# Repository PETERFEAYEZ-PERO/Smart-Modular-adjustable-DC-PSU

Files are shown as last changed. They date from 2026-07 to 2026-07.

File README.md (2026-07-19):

Here is a fully DC power supply with implemented Safety features, real-time MCU control, Voltage & Current adjustment, a cooling system, a wireless charger, and a TFT Display for output voltage.



#  Adjustable Smart Bench PSU

A modular laboratory power supply designed from scratch with
real-time monitoring, protection systems, and scalable multi-output architecture.

# Contents:

1- The main identity and features                                                                              
2- Why DIY, not buy a new, ready-made one?                                                                      
3- list of materials and cost                                                                        
4- The System Architecture flow                                                               
5- The main system Parameters                                                               
6- The automation and building process (METHODS)                                                               
7- Coding-related Part                                                               
8- Documented Failures                                                               
9- Outcome                                                               
10- Safety features and precautions                                                               
11- Upcoming Progress                                                               
12- References                                                               
13- ###<strong>Acknowledgments, refreneces, and AI usage </strong>                                                               
14- Contact                                                               
15- License                                                               

## The Main identity and features:

I had always dreamed about owning an awesome power supply for my projects, a cable to handle various projects, ideas, and testing loads.
Unfortunately, the features, design, and flexibility I need would cost me a lot of money. So I decided to make my own. Additionally, since I had no workshop, tools, devices, or anything, I found it cool to make a full series about building my lab. 

### The Features I was dreaming about:                                                               
1- Adjustable DC power supply ranging from Lim➡️ ZERO to 24V.                                                               
2- Multi-port for output like 4 or 5.                                                               
3- TFT screen of 3.4 inches, rather than 7-segment.                                                               
4- Nice Design.                                                               
5- High Safety features.                                                               
6- one or two AC Ports.                                                               
7- integrated USB HUB                                                             
7- Wireless Charger.                                                               
8- Cooling System.                                                               
9- Data Logging, Graphing, and connection to PC or Lab capability.                                                               
10- Desktop APP                                                               
11- Short Circuit prevention.
12- Battery Charging.                                                               
13- Cable for Modification.                                                                
14- OverVoltage Protection (OVP), OverCurrent protection (OCP), and OverTemperature Protection (OTP)                               
15- Reverse polarity protection
16- Port protection by relay
17- Enclosure design

To find these features in PSU today, it would cost about 10,000 to 30,000 EGP, which is quite expensive for beginners.
For that sake, I made the Making My Lab series, where I will make a full lab device open-sourced for all around the world.
Additionally, you don't have to make the full project; there are versions of this project and other combinations I will provide through the journal file, and the system architecture part in that Readme, so make whatever you need. Also, I am available all of the time to answer your questions and give you help❤️ in any kinda of project, whatever it is. Just Feel Free to go for the Contact part.

## Why DIY, not buy a new, ready one??                                                             
Some people may disagree with my point of view as a maker, and someone aspires to become a mechatronics engineer like me. However, the main purpose for any project u will ever make is to *learn new kinda of stuff!!*

Is that all?    *For sure no!*
The customization and the flexibility are also important points to take into consideration with respect to the needs and price.

## The schematics




## List of materials and cost                                                                        
### The Power section:
#### DC section:-
1) Power Adaptor AC to DC 24V and 10A
2) Power adaptor AC to DC 12V and 5A                                                              
4) XL4016 DC to DC buck converter for each adjustable port                                                                 
6) Terminal Blocks + connectors
7) Wiring
8) Ports                                              

#### AC Power Section:-
External three-AC power strip

#### Wireless Charger module:-
Wireless Charger Module

### The Controlling section:-

1)- THE Microcontroller (MCU):                                    
<ul>
<li> ESP 32 (in case of making the final version)</li>
or 
<li>just any MCU (unless it fits the main parameters of the project)</li>
</ul>

2)- Current Sensor:
<ul>
<li>ACS 712</li>
</ul>

3)- Voltage Calibration circuit (Voltage Divider):-
<incline> under research until now </incline>

4)- Liquid Crystal Display (LCD):
Simply to display the voltage and current for every port, additionally warning in case a short circuit occurs.

5)- Buzzer:
For a short-circuit warning.

6)- Relay module (Fuse integrated) for every port of DC and the wireless charger.

7)- Switch per every DC and the wireless charger.

8)- Circuit of continuous control for the fans and cooling.

### 🌡️ Cooling system & seafty control:

#### Cooling System:
<ol>
<li>SSR Heatsink</li>
<li>Two or three Fans</li>
</ol>

And right here, I made many ventilation holes for the fans, like what is there in the upper case of the USB hub and the PSU too. Additionally, two ventilation holes in the back of the PSU.

#### safety control:
<ol>
<li><strong> Main fuse after the power Adapter </strong></li>
<li>May be added a fuse to every port</li>
</ol>
</br>

# The system architecture flow:
## The power Circuit:
the power shematic drawio

I made this using Draw.io.

## The automation and building Instructions:

### The PSU main Power input and protection
Here are all the instructions u are gonna need:
First of all, for the main power source, I will be using a ready-made Power Adapter of 24 V and 10 A (u could for sure get a better one till 32V as maximum and maybe till 12 amperes. However u will need proper cooling)
Secondly, the Protection circuit, where the (by the same order):
<ol>
  <li>Main Fuse <em>-it is better to use an 11 or 12 amp slow-blow fuse if u are gonna make the system with 10 amps-</em></li>
  <li>A switch -make sure u choose a switch typically to the system power input, or simply choose this switch which cable to shut off, even 220 V and 10 amps-
    
  <li>Transient protection aligned with decoupling capacitors, and yes, I am talking about surge transient protection, not just any overvoltage so make sure u are using transient diode </li>
  <li>Then here is our main system power input of 24v and 10 amps</li>
  

  <li>Finally, i added a relay as a way to shut down the whole system, ensuring safety. In case anything happens.
  I am here controlling the relay with something like an AND gate with an independent switch, and an ESP signal too. We will use the ESP for the relay in case of reverse polarity, overcurrent, overvoltage, or any severe cases. And as far as we go and make an app, we will be able to use WIFI to control the whole system</li>
  
</ol>

### The Power distribution and Outputs:
For the adjustment outputs, I will be using XL4016 for each adjustable output, and I will make them in parallel, for sure so they will all take the same voltage, and the current will be distributed.

And as seen above in the image, I also have one extra constant output taking from the main rail. In conclusion, we have three adjustable outputs and one fixed output.

Additionally, I will be using Relay for each port to manually close and open, or using WIFI.


### The power sensing for each Output:
Think of this as a way for self-parameter monitoring, where the system flows through each port and the total voltage-current consumption.

<strong>For this project, mainly I WILL USE ADC THE MOST, SO I DECIDED TO USE READY ADS MODULE 1115. Just as an alternative to the noisy ESP ADC</strong>

#### For the Current sensing for each port for the XL4016 using ACS712:


Additionally, I will be using a capacitor for each sensor to filter the noise as much as possible. You could simply use this equation to calculate your values. Since the ACS712 also uses a 5V signal, which isn't proper for the ESP PINS, I made all of the signal outputs with 3.3v using voltage dividers.


#### However, for the voltage sensing, I will be using a normal voltage divider connected to the ADS module 1115, like that:


### Then, we finally finished our Power circuit:


## The Control circuit:
The main idea of the PSU is adjustment for the outputs, so how will this work using those XL4016 modules?


The solution is to remove the Timer potentiometer, with a varying DC source of reference 1.25v. However, for the NPN injection transistor or MOSFET, it wouldn't go well.
Thus, after a long search and verification, including the use of Claude, I found that the trimmers can be replaced with a DC source at 1.25V.
So, I used an RC decoupled filter and PWM from the ESP pin; the PWM was filtered to be pure controlled DC.

### Encoders:

And this encoder circuit is mainly for adjustment, where the up and down represent decreasing and increasing the voltage or the current at each port.
Then we need 6 encoders overall.

### Heat sensor and Cooling system:
Here it is, preferable to use an NTC thermistor near the XL4016 modules, and here is the circuit


And for the coolling i made two already open fans, and I added a switch just in case I need to shut them off.

which will be implemented in the back of the PSU.


and one other fan that is working in continuous control with real time montiroing form the ESP directly proportional to the heat in a fully optimal range.

which will be implemented in the upper enclosure of the PSU


### THE ADS module 1115:
Working via I2C


### The power source for the control circuit:
where we got 5v from a LM259 buck converter, aligned with another external power adapter of 12v and 3.3v, also using an LDO voltage regulator.


### The reverse polarity circuit and buzzers:


The full control circuit, except for the ESP:


## The enclosure and 3d printing:
The idea is overall based on modularity, so I decided to make the enclosure of separate parts just in case I need to change a specific part.

### The Upper Part:



### the Bottom part:




### The back part:



### The front part:



### The assembling way:


THEN




THEN



Then, the final assembly:




For assembling the 3D case, I am gonna use a silicone paste. Additionally, the RGB light will be rounded and immersed in the edges of the upper and bottom enclosures. 
And for the outputs of the PSU, I will be using 4 mm Safety Banana Binding Posts and GX16-2

#Acknowledgments and AI usage:
<ul>
<li>My friend SID Batra: the first one who reviewed my early schematics.</li>

<li>those incredible references:</li>
<ol>
  <li> Practical electronics for inventors</li>
  <li>fundamentals of electronic circuits, especially for the FB circuits</li>
</ol>

<li>and Claude AI for the following:
<ol>
<li>Explaining the PID with Simple coding.</li>
<li>Major help in the PID coding part</li>
<li>and most importantly, the CC and CV controlling. I spent a week entirely trying to figure out the way of controlling the XL4016, and yeah, after long frustration through OP-AMPS, FB circuits, and the TL431 architecture. I just found it is better to replace the trimmers with a varying DC voltage source at the wiper</li>
</li>
</ol>
</ul>

###FUN FACT: also, the trimer potentiometer <strong>can't</strong> be replaced by the following for controlling:
<ul>
<li>NPN injection transistor, as it is non-linear and is affected by temperature  change</li>
  <li>same as the same as MOSFET </li>
</ul>

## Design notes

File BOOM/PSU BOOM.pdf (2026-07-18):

# PSU BOOM

- Power Adapter 24V 10A | : 700 EGP y
- 2 * Fuse 10A - Slow blow | : 5EGP
- 2 * Fuse 5A - Slow blow | : 5EGP
- 5 * Fuse Pocket | : 150EGP | (RAM electronics) (https://www.ram-e-shop.com/ar/shop/fuse-pocket5-ver-fuse-pocket-holder-external-for-t5x20-size-vertical-type-5-wqf-8472)
- 2 * Switch with LED | : 20EGP | (RAM electronics) (https://www.ram-e-shop.com/ar/shop/sw1-red-sw1-on-off-switch-with-led-copper-terminals-5735?category=136)
- 3* TVS Doide SMBJ26A | : 17EGP + shipping (AEtronix) (https://eg.aetronix.com/product/taiwan-semiconductor-company/smbj28a/diode-smbj28a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)
- Capacitor kit | : 1505EGP + shipping
Electrolytic cap kit 1105egp (amazon) (https://www.amazon.eg/-/en/Electronics-Capacitor-Assortment-0-1uF-1000uF-10V-50V/dp/B0FDM2MY77) + Cermic cap kit 400egp (amazon) (https://www.amazon.eg/-/en/LIFANG-18values-Monolithic-Capacitor-20pF-1uF/dp/B08CDFZYYC)
- Resistors kit | : 250EGP (RAM) (https://www.ram-e-shop.com/ar/shop/kit-resistor-525-box-of-525-carbon-resistors-1-tolerance-1-4w-lb-mqwmt-qym-mshkl-bdq-ly-1-rb-wt-7642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)
- 6 * Rotary Encode Knob | : 5EGP (RAM) (https://www.ram-e-shop.com/ar/shop/nop-round-knob-for-rotary-potentiometers-kr-bwtynshywmtr-dwr-6639)
- Jumper wires female-female | : 35EGP (RAM) (https://www.ram-e-shop.com/ar/shop/ph62-ff-20cm-ph62-20cm-female-to-female-40-jumper-wires-set-7189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)
- Jumper wires male-male | : 35EGP (RAM) (https://www.ram-e-shop.com/ar/shop/ph61-mm-20cm-ph61-20cm-male-to-male-40-jumper-wires-set-7094?category=36)
- Jumper wires male-female | : 35EGP (RAM) (https://www.ram-e-shop.com/ar/shop/ph60-mf-20cm-ph60-20cm-male-to-female-40-jumper-wires-set-7066?category=36)
- Male Head to Crocodile Alligator Clip: 85EGP (RAM) (https://www.ram-e-shop.com/ar/shop/ph71-m-cro-30cm-ph71-10pin-male-head-to-crocodile-alligator-clip-30cm-long-9197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)
- 4 * End Alligator clip cable black : 280egp (Future electronics) (https://store.fut-electronics.com/collections/cables-connectors/products/copy-of-end-alligator-clip-cable)
- 4* XT60 male to crocodile : 480 EGP (Future electronics) (https://store.fut-electronics.com/collections/cables-connectors/products/xt60female-connector-with-wire-amass-copy-copy)
- Connectors&screw blocks : 100EGP (RAM + Flux)
- Heat shrink kit : 150EGP (RAM) (https://www.ram-e-shop.com/ar/shop/h-sh-set-530-color-box-of-heat-shrink-530pcs-set-color-lb-shrnk-mkrwn-hrry-ll-zl-mlwn-530-qt-7712)
- Wire Ferrules | : 80EGP +shipping (amazon) (https://www.amazon.eg/-/en/Terminal-Insulated-Connecting-Connectors-E1006/dp/B0DRGPMXJ8?th=1)
- Heat Transfer Paste | : 250EGP (RAM) (https://www.ram-e-shop.com/ar/shop/compound-aptl-paste-50gm-heat-transfer-paste-50gm-thermal-grease-nbwb-lsq-wm-jwn-hrry-llmbrdt-llwmnywm-8890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)
- Soldering wire : 400EGP (RAM) (https://www.ram-e-shop.com/ar/shop/solder-wire-ram-100gm-solder-wire-ram-high-quality-100gm-sn70-pb30-qsdyr-lhm-ly-ljwd-mrk-rm-bkr-100jm-nsb-lqsdyr-l-lrss-70-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)
- Solder Weck : 110 EGP (RAM) (https://www.ram-e-shop.com/ar/shop/atten-at0815-wicker-atten-r-at-0815-solder-wicker-width-0-8mm-length-1-5m-shyld-qsdyr-lfk-lhm-lmkwnt-mrk-tyn-9583)
- Flux : 185 EGP (RAM) (https://www.ram-e-shop.com/ar/shop/solder-paste-blue-50gm-xg-50-repair-soldering-solder-past-welding-35g-m-jwn-qsdyr-llslht-wllhm-wzn-35-jm-6966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)
- Rounded sponge : 15 EGP (RAM) (https://www.ram-e-shop.com/ar/shop/sponge-50mm-china-replacement-sponge-for-soldering-iron-stand-round-50mm-sfnj-hml-kwy-dyry-qtr-50mm-5740)
- ZENER DIODE ASSORTMENT PACK: 115EGP (UGE) (https://uge-one.com/product/2-4v-33v-0-5w-zener-diode-assortment-pack-25-values-pack-of-250-pcs/)
- 4 * XL4016 | : 215 (Ampere) (https://ampere-electronics.com/product/xl4016-dc-dc-step-down-converter-module-12a-300w/)
- 5 * ACS712 current sensor | : 500 (RAM) (https://www.ram-e-shop.com/ar/shop/kit-cs-dc-30a-acs712-ac-dc-30a-current-sensor-module-acs712-30a-7277)
- 6 * Switch | : 30EGP (RAM) (https://www.ram-e-shop.com/ar/shop/sw2-black-2pin-sw2-on-off-switch-2-pin-copper-terminals-5736)
- Relay 4 Channel Module : 130EGP (AMPERE) (https://ampere-electronics.com/product/relay-module-4-channel-5vdc/)
- 3 * LM2596s buck converter : 135EGP (RAM) (https://www.ram-e-shop.com/ar/shop/dc-dc-100-dc-dc-step-down-converter-adjustable-3a-lm2596s-4-38vdc-to-1-5-35vdc-sku-dc100-bwrd-dyr-khfd-jhd-fwlt-7257)
- 4 * Rotary encoder | : 100 (RAM) (https://www.ram-e-shop.com/ar/shop/pot-ec11-rotary-5pin-20mm-ec11-rotary-encoder-with-push-button-switch-5pin-20mm-silver-9624)
- 4 * Buzzer 5v | : 30 (AMPERE) (https://ampere-electronics.com/product/5vdc-pcb-mount-buzzer/)
- Power Adapter 12v 5a | : 300EGP + shipping(Microhm) (https://microohm-eg.com/ac-dc-hopson-12v-5a-power-adapter-high-quality/)
- ESP32-S3 (DevKitC-1) | : 550EGP Future electronics
- AMS1117 3.3v : 3EGP (RAM) (https://www.ram-e-shop.com/ar/shop/lt1117-3-3v-ams1117-3-3v-6628)
- Wireless supply module : 120 EGP (AMPERE) (https://ampere-electronics.com/product/5v-1a-wireless-power-supply-charging-module/)

- Wireless receiver module | : 225EGP (FLUX) (https://fluxelectronix.com/shop/5w-qi-wireless-charger-receiver-module/)
- USBs | : 50 (RAM)
- USB plastic cover | : 50 (RAM) (https://www.ram-e-shop.com/ar/shop/usb7-type-a-female-usb2-0-type-a-female-plug-4-pin-connector-jack-with-plastic-cover-sku-usb7-7494)
- ESP cable | : 50 (RAM)
- NTC thermistor | : 40 (RAM) (https://www.ram-e-shop.com/ar/shop/wire-ntc-10k-m-ntc10k-metal-head-thermistor-sensor-with-cable-sku-wire-ntc-7008)
- Fan 12025 24v | : 160 (ampere) (https://ampere-electronics.com/product/12038-cooling-fan-24vdc/)
- 2* Fan 4020 5v : 80 (ampere) (https://ampere-electronics.com/product/4020-cooling-fan-5vdc-40x40x20mm/)
- 6025 fan 12v : 60 EGP (AMPERE) (https://ampere-electronics.com/product/6025-cooling-fan-12vdc-60x60x25mm/)
- Breadboard | : 350 (RAM) (https://www.ram-e-shop.com/ar/shop/bb3t5d-bb-bb-3t5d-breadboard-2390-tie-point-metal-base-bryd-bwrd-m-q-d-m-dny-3-qt-6756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)
- 6 * IRLZ44N : 96 (Microhm) (https://microohm-eg.com/irfz44-n-channel-mosfet/)
- 2*IRF4905 : 100 (Mircrohm) (https://microohm-eg.com/irf4905-p-channel-hexfet-mosfet/)
- 4* Zener Diode 12V 1/2w BZX55C12V: 2EGP (Microohm) (https://microohm-eg.com/zener-diode-12v-1-2w/)
- 6 * 1N4148 : 3EGP (RAM) (https://www.ram-e-shop.com/ar/shop/1n4148-1n4148-high-speed-fast-switching-diode-300ma-100v-dywd-sry-5636)
- XL4016 with display : 340 EGP (amazon) (https://www.amazon.eg/-/en/Charge-Module-XL4015-Adjustable-Display/dp/B0B6SR4917)
- Heatsink Thermal Compound Paste : 35EGP (AMPERE) (https://ampere-electronics.com/product/hf-190-heatsink-thermal-compound-paste/)
- 2 * Heat Sink : 125 EGP (Ampere) (https://ampere-electronics.com/product/solid-state-relay-heat-sink-i-50mm/)
- 4 * Small heatsink : 20 EGP (AMPERE) (https://ampere-electronics.com/product/heatsink-to-220-25x14x10mm/)
- Colling Fan grill 60mm | : 60 EGP (AMPERE) (https://ampere-electronics.com/product/heatsink-to-220-25x14x10mm/)
- Ring terminals / fork terminals | : 50 EGP
- Proper wire | : 100EGP
- 12v White LED strip | : 545 EGP (Amazon) (https://www.amazon.eg/-/en/Flexible-Strip-High-Intensity-White/dp/B0CKNF3316)
1. Soldering Iron | : 6.5$
2. Wire Stripper With Holes | : 2$
3. Tweezer Angled | : 2$
4. Soldering wire, wick, flux, sponge | : 14.2$
5. USB Seafty tester UT658 | : 9$
6. Small Multimeter | : 10$

### The sharble PSU boom

4*Xl4016 Dc/Dc buck converter | : 17.5$
XL4016 with display | : 7$ | (amazon) (https://www.amazon.eg/-/en/Charge-Module-XL4015-Adjustable-Display/dp/B0B6SR4917)
ESP32-S3 (DevKitC-1) | : 11$
Power adapter 24V 10A | : 14$
Fuses, fuse pockets, Switches | : 4.4$
3*TVS Doide SMBJ26A | :1.5$
capcitors+resistors+Buzzers | : 35.7$
Rotary encoders + knobs | : 3.6 $
Jumper wires + crocodile clips + Wire stripper + connectors and srew blocks + wire ferrules + proper wires + Ring terminals / fork terminals: 25.6$
Heat shrink kit | : 3$
Heat transfer paste | :5.7$
Zener diode kit+other diodes | : 4.3$
Relay 4 Channel Module | : 2.6$
3 * LM2596s buck converter | : 2.7$
Power Adapter 12v 5a | :6$
AMS1117 3.3v | : 0.06$
Wireless supply and receiver module:6.9$
5 * ACS712 current sensor | : 10$
USBs+USB plastic cover | : 2$
ESP cable | : 1$
NTC thermistor | : 0.8$
Fans+fan grills | : 7.2$
Heatsinks | : 2.9$
Transistors | : 4$
Big Breadboard | :7$
TFT Touch Screen Display ESP | : 18$
External AC subscriber | : 8$
White Led strip | : 10.9$

Total: 212 $

Tools if available:
- Soldering Iron | | : 6.5$
- Wire Stripper With Holes | | : 2$
- Tweezer Angled | | : 2$
- Soldering wire, wick, flux, sponge | : 14.2$
- USB Seafty tester UT658 | | : 9$
- Small Multimeter | | : 10$

Total of tools: 43.7 $

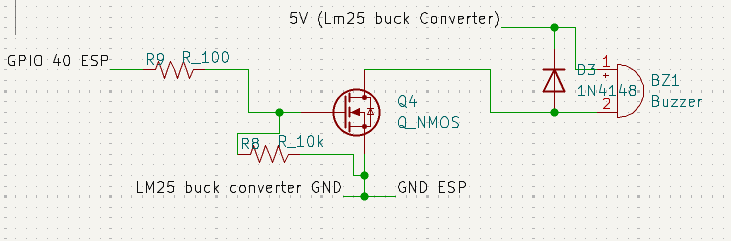
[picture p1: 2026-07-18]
Images gallary/PCB pervious versions images/Screenshot 2026-06-08 002814 - Copy.png

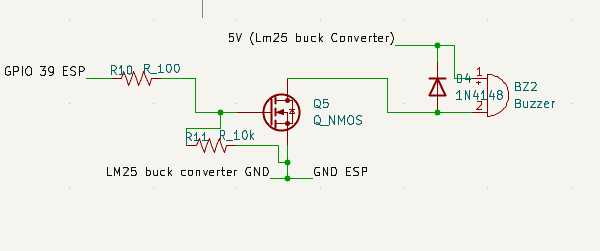
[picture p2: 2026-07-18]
Images gallary/PCB pervious versions images/Screenshot 2026-06-08 072103.png

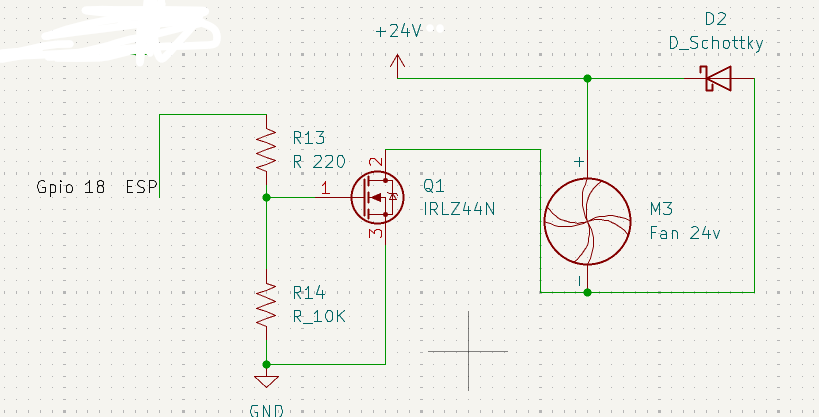
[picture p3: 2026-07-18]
Images gallary/PCB pervious versions images/Screenshot 2026-06-07 054425 - Copy.png

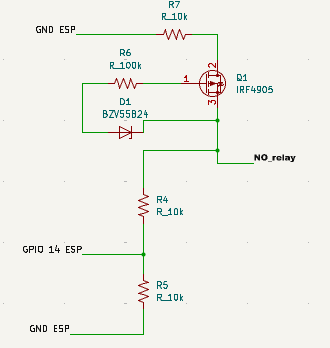
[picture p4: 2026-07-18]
Images gallary/PCB pervious versions images/Screenshot 2026-06-08 000533 - Copy.png

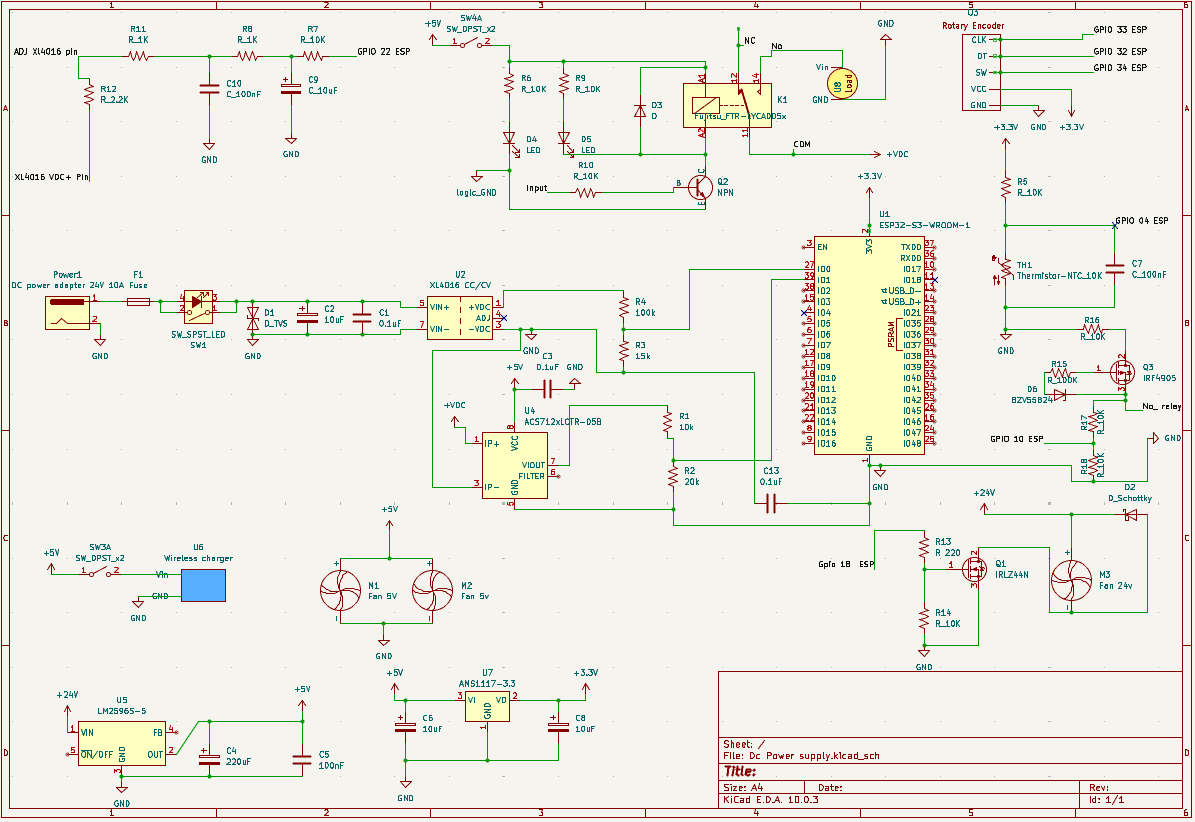
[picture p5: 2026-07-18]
Images gallary/PCB pervious versions images/Screenshot 2026-06-07 201926 - Copy.png

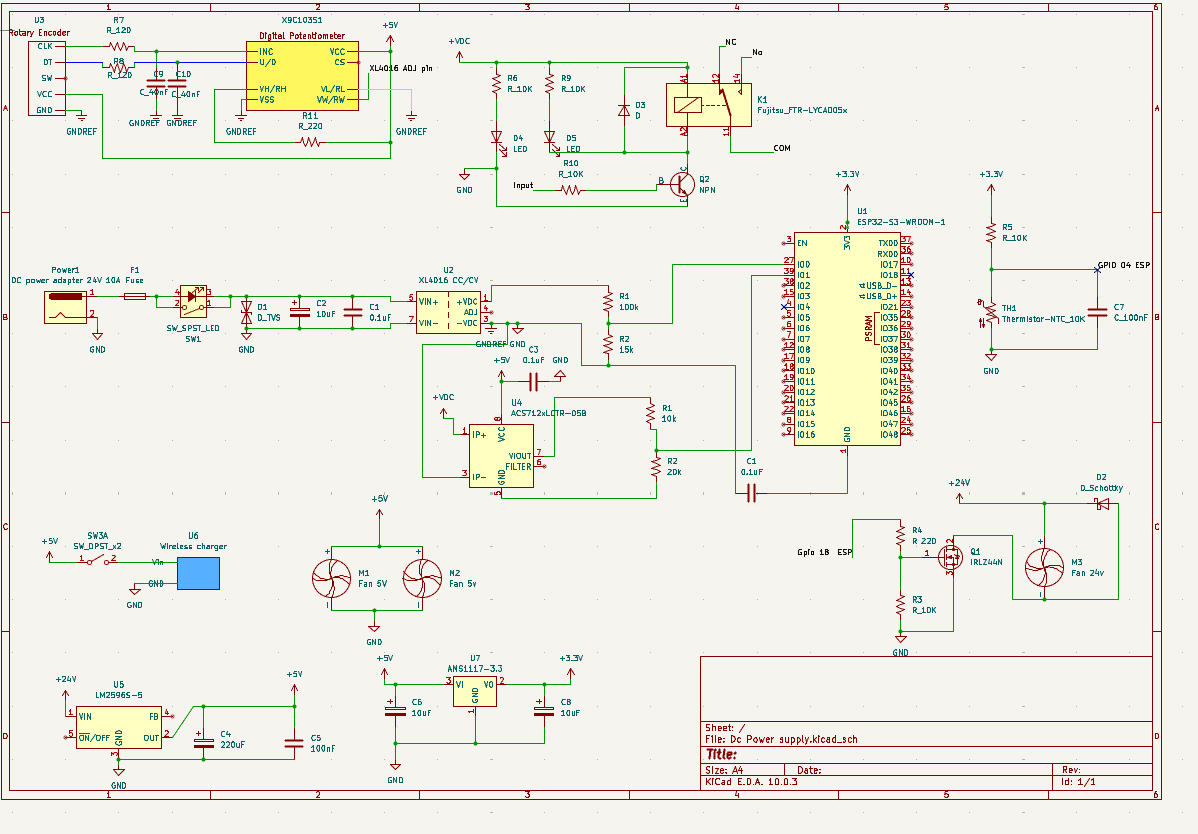
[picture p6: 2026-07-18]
Images gallary/PCB pervious versions images/Screenshot 2026-06-07 031731 - Copy.png

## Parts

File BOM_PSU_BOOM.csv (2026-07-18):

Category | Component | Quantity | Unit Cost (USD) | Total Cost (USD)
Power Stage | XL4016 DC/DC Buck Converter | 4 | 17.5 | 70
Power Stage | XL4016 with Display | 1 | 7 | 7
Controller | ESP32-S3 DevKitC-1 | 1 | 11 | 11
Power Input | 24V 10A Power Adapter | 1 | 14 | 14
Protection | Fuses + Fuse Holders + Switches | 1 | 4.4 | 4.4
Protection | SMBJ26A TVS Diodes | 3 | 0.5 | 1.5
Passive | Capacitor + Resistor + Buzzer Kits | 1 | 35.7 | 35.7
UI | Rotary Encoders + Knobs | 1 | 3.6 | 3.6
Accessories | Jumper wires, clips, stripper, connectors, ferrules, wires, terminals | 1 | 25.6 | 25.6
Assembly | Heat Shrink Kit | 1 | 3 | 3
Thermal | Heat Transfer Paste | 1 | 5.7 | 5.7
Protection | Zener Kit + Other Diodes | 1 | 4.3 | 4.3
Switching | 4-Channel Relay Module | 1 | 2.6 | 2.6
Power | LM2596 Buck Converter | 3 | 0.9 | 2.7
Power | 12V 5A Power Adapter | 1 | 6 | 6
Regulation | AMS1117-3.3V | 1 | 0.06 | 0.06
Wireless | Wireless Supply + Receiver | 1 | 6.9 | 6.9
Sensing | ACS712 Current Sensor | 5 | 2 | 10
Connectivity | USB Connectors + Covers | 1 | 2 | 2
Connectivity | ESP USB Cable | 1 | 1 | 1
Sensing | NTC Thermistor | 1 | 0.8 | 0.8
Cooling | Fans + Fan Grills | 1 | 7.2 | 7.2
Cooling | Heat Sinks | 1 | 2.9 | 2.9
Semiconductors | Transistors | 1 | 4 | 4
Development | Large Breadboard | 1 | 7 | 7
Display | ESP TFT Touch Screen | 1 | 18 | 18
Power Input | External AC Socket | 1 | 8 | 8
Lighting | White LED Strip | 1 | 10.9 | 10.9
 |  |  | Total | 212

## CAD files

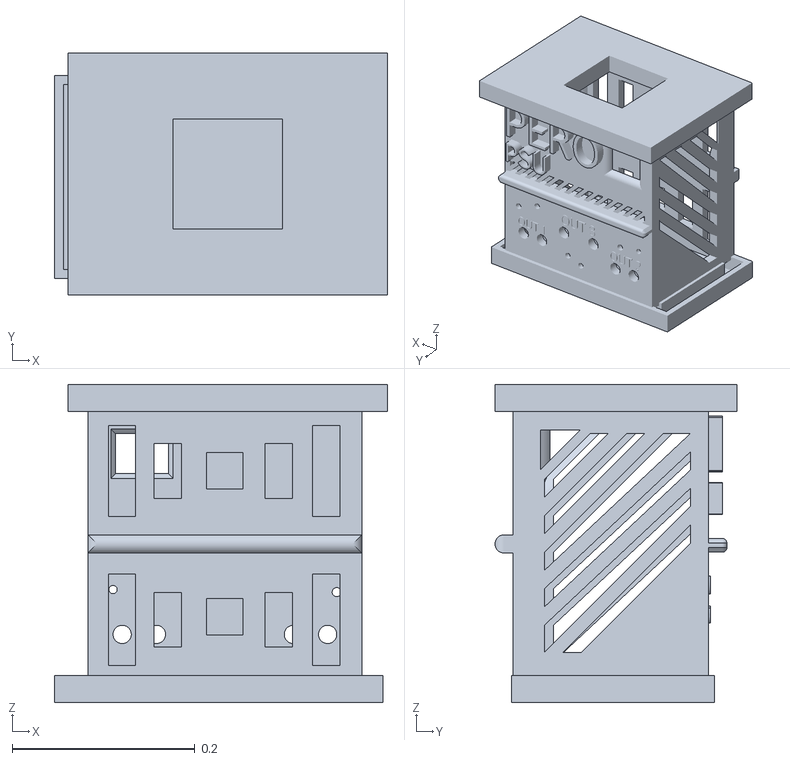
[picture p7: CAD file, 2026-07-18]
3D Assembly/The Main PSU/Assembly PSU.stl
0.365 x 0.265 x 0.349

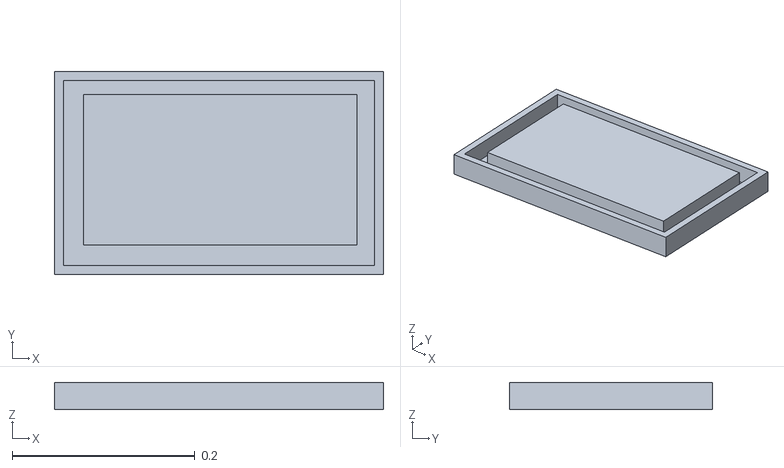
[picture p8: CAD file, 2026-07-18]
3D Assembly/The Main PSU/the upper case (2).stl
0.36 x 0.223 x 0.03

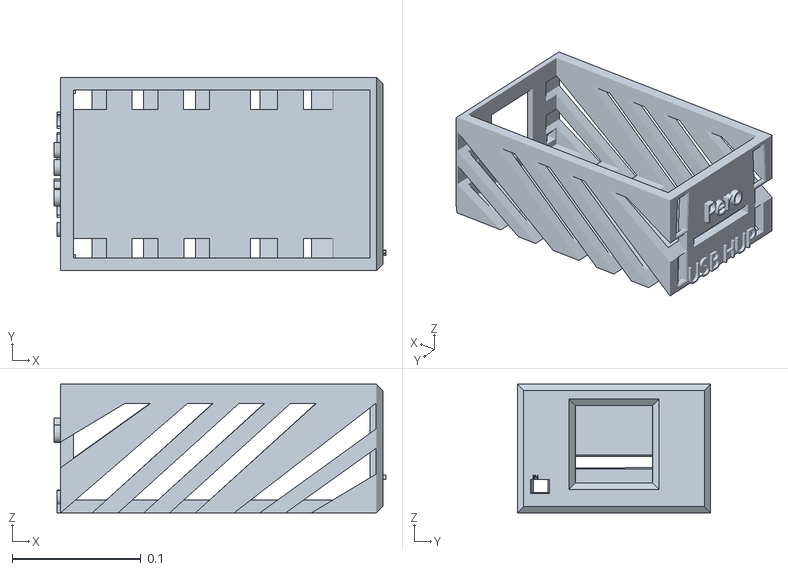
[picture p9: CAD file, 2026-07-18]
3D Assembly/USB HUB/The USB HUP base case.stl
0.257 x 0.15 x 0.1

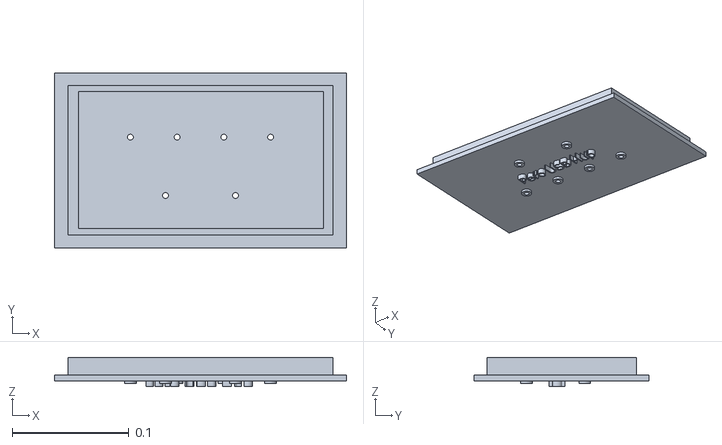
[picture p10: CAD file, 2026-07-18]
3D Assembly/USB HUB/the upper case.stl
0.25 x 0.15 x 0.025

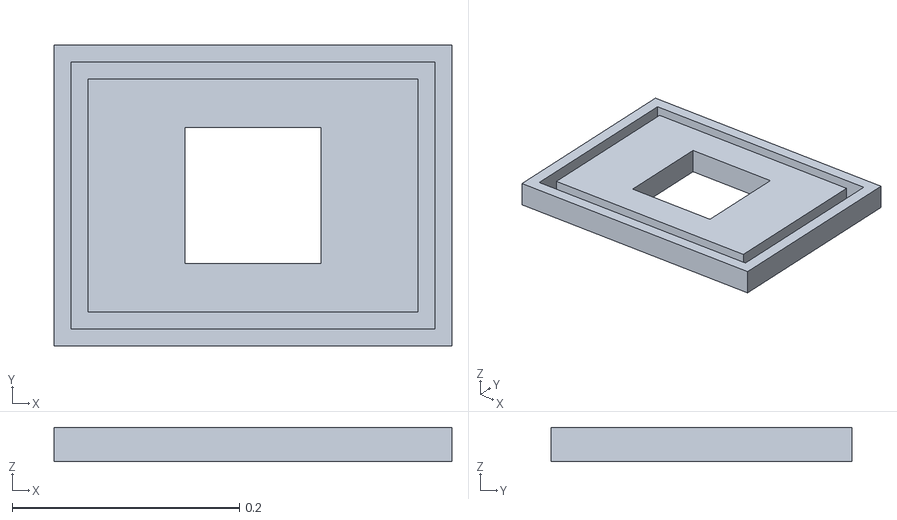
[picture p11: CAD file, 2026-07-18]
3D Assembly/The Main PSU/the Lowwer base.stl
0.35 x 0.265 x 0.03

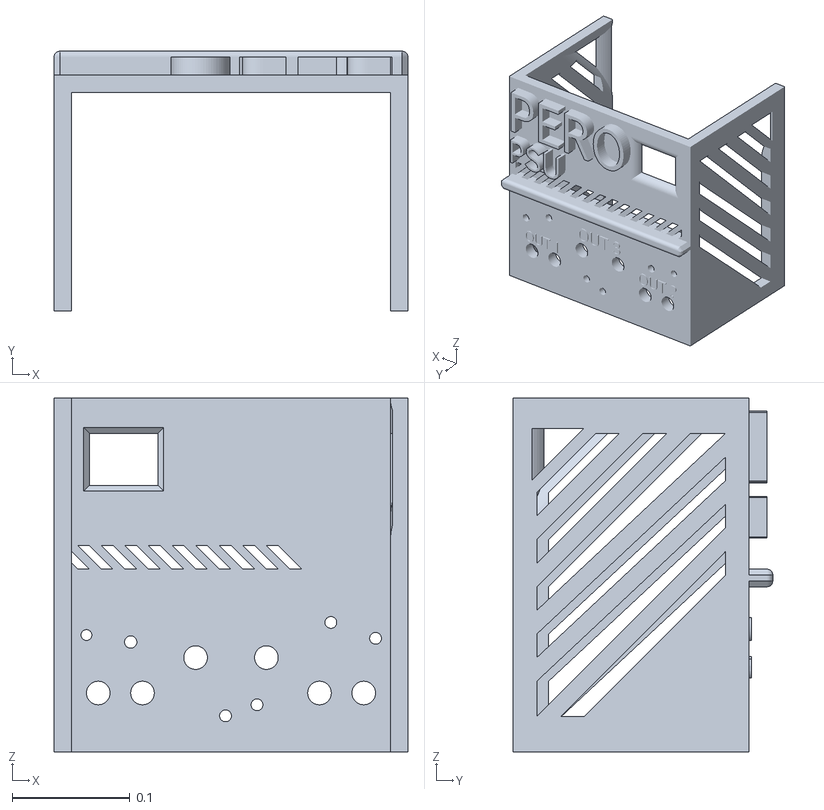
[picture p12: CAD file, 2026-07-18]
3D Assembly/The Main PSU/the front face PSU.stl
0.3 x 0.22 x 0.3

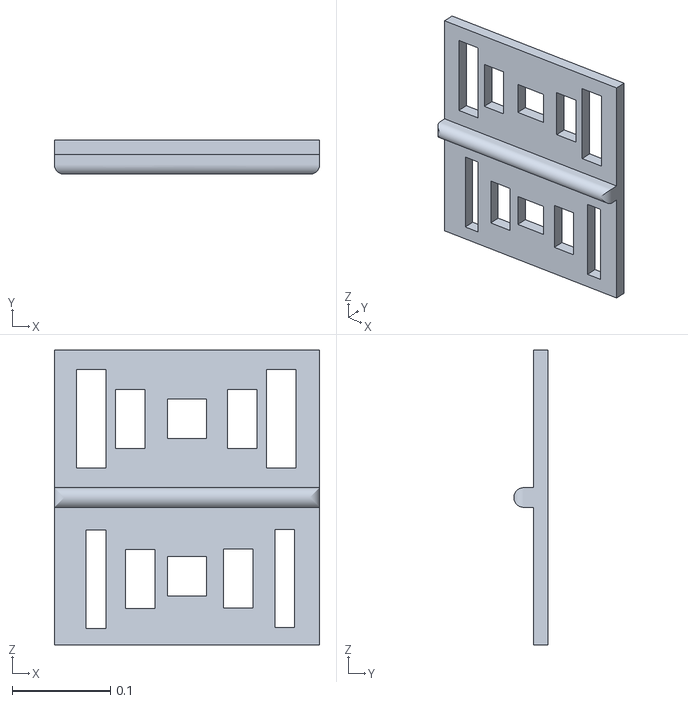
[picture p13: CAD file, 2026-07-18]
3D Assembly/The Main PSU/Back face.stl
0.27 x 0.035 x 0.3

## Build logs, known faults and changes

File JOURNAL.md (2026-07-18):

---
title: "Smart Adjustable PSU"
author: "Peter Fayez."
description: "This is a power supply 24V and 10A, with 4 adjustable output ports, with transient protection, overcurrent, overvoltage, and overtemperature protection. Additionally, it is added with a wireless charger module, a USB Hub, Remote Controlling, cooling system(Urgent+dominant), PC/andriod App, TFT touch screen, and Smart using Wi-Fi.
"
created_at: "2026-06-01"
---

The full idea: circuit design, components, CAD design, enclosure, and CFD cooling model are made entirely by me.
You can use my Readme record as some sort of check cuase i wasn't konw about journaling, so it is believable that it may have found some of the unmatched timing because I wasn't introduced to hackatime, lapses, or even journaling yet. I just got started.

# June 1: Begin search, study power electronics, write my parameters:
This was my actual first step as a new member in the electronics and hack club, too. I had barely enough electronics knowledge to understand the theoretical perspective of electricity and power conversion. So, I began to study, making my first flow chart with draw IO that took about 3 hours, including several mistakes and overkill misconceptions in basic power and wiring concepts, especially for the surge protection.



**Total time spent: 3 hours**

# June 2: Begin search, study power electronics, write my parameters:
This was a more detailed version, as I not only began the flow, but I began to figure out what components and wiring I would have. That drawing takes me about 4 hours!!


Additionally, I had begun my first Kicad schematic ever in my entire life, and for the first hour, I was lagging. Fortunately, after some time, I began to figure out how things work!! And then I got another couple of hours trying to make this schematic.
I also spent a bunch of hours that day on some of the kidac tutorials and some of the power electronics reading books and courses.

**Total time spent: 7 hours**

# June 2: searching for the PSUs' parameters and features + trying to add some of the work to Draw. io. and my schematic:
I was searching for about two hours or maybe even much more (unfortunately, I wasn't introduced to lapsing, so I don't have screen records of the full search, but, predictably, it will exceed two hours) just searching for such things as the smart DC power supply, power output, design, and screens too so I can come up with clearer insight.

Also, I edited a little bit on the first schematic; I tried to make it cleaner. That takes about an hour.

**Total time spent: 3 hours**

# June 3: some kinda of improvements and learning
Also, I tried to add a lot of the things in the schematic that take about 1 hour.

Also, I made a circuit for the urgent fan in case of high TEMP! This takes me about half an hour.

Additionally, I had started searching for the components' availability in Egypt and the alternatives, which had much more at this stage. That was about 2 hours.
**Total time spent: 3.5 hours**

# June 4: the CV and CC adjustment discovery by the XL4016
This is the first day I understood how the FB pins in the XL4016 were really working and how it is adjusted to a ref. of 1.25v. Here is the core of the adjustable power supply emergent, and how it could be the Potentiometer replaced with encoders(my dream!!!!)
That research about available options takes me about 4 hours.


And yes, I began to be hopeful that I came up with a more detailed approach to the digital potentiometer.

The MCP digital potentiometer. The worst electronics concept I've ever encountered!!
I had been studying that kinda of digital potentiometer of MCP!! And I made the entire circuit of the digital potentiometer, encoder, ESP 32 WROOM 32 pins! I spent 3 hours making that circuit. 
(Unfortunately, I didn't take any screenshots for this version of the schematic!)

**Total time spent: 7 hours**

# June 5: The Shock!! 
The MCP Dital potintiometers aren't avalbile on egypt!!! So, I tried to search for another option.
This was the hardest part as I needed to shift to the available option of DAC: X9C103S Digital Potentiometer module (10Kohm), which is even unsuitable with the parameters of the XL4016 pins (I had discovered that later). 
This takes me about 3 hours of searching, making a circuit, and trying to figure out the firmware by the ESP!!! 

Also, that day I made more detail shematic adding the NTC thermistor and relay connection!!!

This takes me off overall by two hours!

**Total time spent: 5 hours**

# June 6: Replacing the inefficient and unsuitable X9C103S with the DAC built in the ESP32 s2, then with the PWM
This was the time I found I can't actually use that module, also it was so complicated, and may be i would need a two-layer PCB to achive teh indeed design

So, I made my first schematic for that, and it has two wrong aspects: firstly, the GPIO 33 wasn't even a DAC😂. Secondly, the ADJ pin of the XL4016 is connected to the main supply rail, which will cause it to blow up, or just the Feedback loop gets destroyed!!!


Whenever I simulate that part or ask Gemini or ChatGPT (both of them are bad, really baaaaaaaaaaaaaaaaaaaaaaaaaaaaaaaaaaaaaaaaad!!!!!). They were providing counterintuitive opinions. I remained stuck on that for about an hour, entirely trying to figure out what was going on. Until I revise the data sheet of the XL4016, as it had to be connected to the Vout+ pin!!!, where I also find that the filtered PWM can be much better than that of the DAC.



simi- final schematic!!

Draw io. final flow chart edit:


This was a long Day!!!!!!

**Total time spent: 6 hours**

# June 7: adding some of the details

I added the circuit of the relay once again (mistake)

That takes half an hour

Also, I made the first power rail schematic, which is much better for the final fabrication

and some of the buzzers' circuits:



**Total time spent: 2.5 hours**

# June 8: making each of the power and control rail full independently!
That day, I discovered I won't be making one PCB integrating all of that system. I decided to split the PCBs into power rail and control rails, also decreasing the noise and electronic fluctuations as much as possible. So I made:
Control rail!!

Where the ESP, Fans, NTC, ETC...
Power rail!!

Where the relay, XL4016, Etc...

**Total time spent: 3 hours**

# June 9: USB Hub!!
This was my actual beginning with the USB Hub. I was juggling between research, cooling, brainstorming, finding good internet ideas, and calculating the actual Ampere and voltage I need, respectively, to meet my parameters.
I take about four hours, thus I need a separate power adaptor of 12V and 5A using another XL4016 with a display for operating 4 type-A female USBs and two Type-C USBs.


Also, I had chosen all of the materials I needed. 
One's choice was hard, but the most difficult is the choice of the fan, either it's opperation method or even dimensions!!
I chose after a long brainstorming session, I chose to use a simple switch; however, I will leave it open all of the time.
Additionally, I made the Type-C as a rail and the Type-A USBs as another rail parallel to each other, adding a small cool feature:
Although I added a fuse to each rail, what if the fuse just blew out(in case of connection of the four USBs with huge current devices)? Then my family will wait until Peter comes from the trip to find a way to fix that thing?
So, added within each rail to parallel rails leading to the USB's rail, one with only a fuse and the other with a closed switch and fuse, so that the first fuse blew out. We will be able to operate the same rail in another way.
And for the cooling: I was so confused choosing a 12025 fan or a 6015 fan, as the bigger dimensions it is, the quieter it became(good deal!), but less RPM(Bad deal). I chose the 6015 fan for proper cooling, and also after I found that the USB hub had to be relatively small.


**Total time spent: 4 hours**

# June 11:The Boom and materials writing on Google spreadsheet!
I know it sounds crazy that someone will take three hours to write the BOOM, but how things go in Egypt Cuz i don't know what is available or not, and there is no unified price. Additionally, I may need to categorize the materials into sublists from every shop, which takes much time.


I know it may sound a little bit unbelievable!!
**Total time spent: 3 hours**

# June 12: Cad with ONSHAPE

https://lapse.hackclub.com/timelapse/p3Fguz1rJplR
https://lapse.hackclub.com/timelapse/XrkDsW8N9rKd
https://lapse.hackclub.com/timelapse/pcyGR5MnPfYz
https://lapse.hackclub.com/timelapse/gKYMVtGurDUY
https://lapse.hackclub.com/timelapse/yevhhOZqur6d
https://lapse.hackclub.com/timelapse/zA62v7QnH9z3


**Total time spent: 6 hours and a quarter of an hour**

# June 18: re-CAD the whole project and coding 
I found that the whole project enclosure case is not that perfect and is missing a lot of things, even the ports of the outputs and the TFT, so I decided to make another one in the shape of a house, for the sake of making a workbench power supply. Additionally, I made it in a modular way as it can be assembled or separated in onyl one minute and for ht esake the whole project i was inspired by the way framework making thier products so why i amn't adopting this technology? 
















lt="Screenshot 2026-07-17 235530" src="https://github.com/user-attachments/assets/b111d489-329a-47e2-9a9c-e2131ac42f36" />
addtionally i wrote the full code, and mistakenly I found myself already stopped all of the extensions in vs code includeing WAKA time so the whole code of 700 lines and a bunch of other crazy comments I wrote, counted only as one hour 
as shown here in the repo the python source code also https://github.com/PETERFEAYEZ-PERO/Smart-Modular-adjustable-DC-PSU/blob/main/PSU-code.py 

**The total time working on that project till now is: 52 hours**

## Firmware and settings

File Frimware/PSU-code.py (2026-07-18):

# main.py - PSU BOOM frimware (Micropython, #ESP32-S3 | 3x XL4016 CC/CV | 2x ADS1115 | ST7789 TFT | 6 encoders
#  4 relays | 2 buzzers | NTC | fan | protection | PID and no thing else just the worst code ever written.
# ==========================

from machine import Pin, I2C, ADC, PWM, SPI, Timer
import time
import framebuf
import struct
import gc

try:
    import netwrok
except ImportError:
    nnetwork = None

#PWM outputs -> RC filter -> XL4016 CV/CC trimmer pads
PWM_PINS = {
    "cv1": 4, "cc1": 5,
    "cv2": 6, "cc2": 7,
    "cv3": 15, "cc3": 16
}
PWM_FREQ = 20000  # 20kHz
PWM_DUTY_MAX = 4095  # HERE peter this is the frequency u forget it every time u are reviewning and plz don't touch this unless u recalculate the impedance plz peter plz!!!!

I2C_SCL=9
I2C_SDA=8
ADS1_ADDR=0x48 #this si the output of the first xl4016 where V/I sensores and the second xl4016 so u had to check it for the I2C 
ADS2_ADDR=0x49

#The TFT i love!! (SPI, ST7789)
TFT_SCK=14
TFT_MOSI=13
TFT_CS = 10
TFT_DC = 11
TFT_RST=12
TFT_BL=17
TFT_W, TFT_H = 240, 135

=
Relay_pins = {"out1": 18, "out2": 21, "out3": 38, "main": 39}




#those cringy buzzers
BUZZER_PROTECTION_PIN=40
BUZZER_REVERSEPOULARITY_PIN=41

#THE FANS RORORORO 
FAN_PWM_PIN=42
FAN_FREQ=25000


#THE ADOPTED ntc thermistor
NTC_PIN=1


#THIS CIRCUIT IS THE WORST EVER THE PROTECTIO FROM POULARITY
REVERSEPOULARITY_PIN=2

#the encoooocococooooooococooooders where the CLK dt sw
    ENCODER_PINS = {
        cv1: {"clk": 45, "dt": 46, "sw": 47},
        cc1: {"clk": 48, "dt": 35, "sw": 36},
        cv2: {"clk": 37, "dt": 3, "sw": 0},
        cc2: {"clk": 19, "dt": 20, "sw": 33},
        cv3: {"clk": 34, "dt": 26, "sw": 27},
        cc3: {"clk": 28, "dt": 29, "sw": 30}
    }


V_OUT_MIN_MV = 800
V_OUT_MAX_MV = 24000
I_OUT_MIN_MA = 0
I_OUT_MAX_MA = 5000

OVP_TRIP_MV = 24500
OCP_TRIP_MA = 5300
OTP_TRIP_C = 75.0
UVLO_MV = 20000

VSENSE_DIVIDER_RATIO = 19.0
ACS712_MV_PER_A = 185.0
ACS712_DIVIDER_RATIO = 0.4048

NTC_NOMINAL_OHM = 10000
NTC_NOMINAL_TEMP_C = 25.0
NTC_BETA = 3950.0
NTC_SERIESOHM = 10000.0

FAN_TARGET_TEMP_C = 45.0
FAN_KP = 12
FAN_MIN_DUTY = 60
FAN_MAX_DUTY = 255



V_STEP_MV = 10
V-STEP_MA = 10

FUALT_NONE, FUALT_OVP, FAULT_OCP, FAULT_OTP = 0, 1, 2, 4
FAULT_REVPOL, FAULT_UVLO, FAULT_FAN = 8, 16, 32



# THE ADS SHITTY DRIVER -HOLD ON AT LEAST U KNOW ALREADY WHERE I WILL BACK AGIAN TO KICK THAT 

class ADS1115:
    REG_COVERT = 0x00
    REG_CONFIG = 0x01
    GAIN_MV_PER_EACHCOUNT = 0.1875  

    def__init__(self, i2c, addr):
        self.i2c = i2c
        self.addr = addr
        self.ok = self.probe()
    
    def probe(self):
        try:
            self.i2c.writeto(self.addr,b'\x00')
            return True
        except OSError:
            return False
        
    def read_single_ended(self, channel):
        if not self.ok or channel > 3:
            return 0
        mux = 0x04 + channel
config = 0x8000          
        config |= (mux & 0x07) << 12
        config |= 0x0000          
        config |= 0x0100          
        config |= 0x0080           # 128 SPS
        config |= 0x0003 
        try:
            self.i2c.writeto_mem(self.addr, self.REG_CONFIG, struct.pack('>H', config))
            time.sleep_ms(8)  
            data = self.i2c.readfrom_mem(self.addr, self.REG_COVERT, 2)
            raw = struct.unpack('>h', data)[0]
            voltage_mv = raw * self.GAIN_MV_PER_EACHCOUNT
            return voltage_mv
        except OSError:
            return 0

    def read_mv(self, channel):
        return self.read_single_ended(channel) * self.GAIN_MV_PER_COUNT



class st7789:
     def __init__(self, spi, cs, dc, rst, width, height):
          self.spi = spi
          self.cs = cs
          self.dc = dc
          self.rst = rst
            self.width = width
          self.height = height
          self.buffer = bytearray(self.width * self.height * 2) 
          self.fb = framebuf.FrameBuffer(self.buffer, self.width, self.height, framebuf.RGB565)
          cs.init(cs.OUT, value=1)
          dc.init(dc.OUT, value=0)
          rst.init(rst.OUT, value=1)
          self._init_display()

    def_write_cmd(self, cmd):
        self.cs(0)
        self.dc(0)
        self.spi.write(bytearray([cmd]))
        self.cs(1)
def _write_data(self, data):
        self.cs(0)
        self.dc(1)
        self.spi.write(data if isinstance(data, (bytes, bytearray)) else bytearray([data]))
        self.cs(1)

    def _init_display(self):
        self.rst(0)
        time.sleep_ms(50)
        self.rst(1)
        time.sleep_ms(50)
          self._write_cmd(0x01); time.sleep_ms(150)   # SWRESET
        self._write_cmd(0x11); time.sleep_ms(255)   # SLPOUT
        self._write_cmd(0x3A); self._write_data(0x55)  # 16-bit color
        self._write_cmd(0x36); self._write_data(0x00)  # MADCTL
        self._write_cmd(0x21)                        # i am guising it is true as it is common to use 0x21 for inversion on ST7789, but it may vary based on the specific display module so so so sos oso agian and agian and agian if u are gonna troubleshoot or somehting like that check this too may be the issue layes right here
        self._write_cmd(0x13)                        # NORON
        self._write_cmd(0x29); time.sleep_ms(100)     # DISPON

    def _set_window(self, x0, y0, x1, y1):
        self._write_cmd(0x2A)
        self._write_data(struct.pack('>HH', x0, x1))
        self._write_cmd(0x2B)
        self._write_data(struct.pack('>HH', y0, y1))
        self._write_cmd(0x2C)

    def show(self):
        self._set_window(0, 0, self.width - 1, self.height - 1)
        self.cs(0); self.dc(1)
        self.spi.write(self.buf)
        self.cs(1)

    def show(self):
        self._set_window(0, 0, self.width - 1, self.height - 1)
        self.cs(0); self.dc(1)
        self.spi.write(self.buf)
        self.cs(1)

    def fill(self, color): self.fb.fill(color)
    def text(self, s, x, y, color=0xFFFF): self.fb.text(s, x, y, color)
    def pixel(self, x, y, color): self.fb.pixel(x, y, color)
    def rect(self, x, y, w, h, color, fill=False):
        if fill: self.fb.fill_rect(x, y, w, h, color)
        else: self.fb.rect(x, y, w, h, color)


COLOR_BLACK  = 0x0000
COLOR_WHITE  = 0xFFFF
COLOR_RED    = 0xF800
COLOR_GREEN  = 0x07E0
COLOR_YELLOW = 0xFFE0
COLOR_CYAN   = 0x07FF

#the PIIIIIIIIIIIIIIIIIIIIIIIIIIIIIIIIIIIIIIIIIIIIIIIIID I ADORE PID 
class PID:
    def __init__(self, kp, ki, kd, out_min=0, out_max=4095):
        self.kp, self.ki, self.kd = kp, ki, kd
        self.out_min, self.out_max = out_min, out_max
        self.integral = 0.0
        self.last_error = 0.0
        self.last_time = time.ticks_ms()

    def reset(self):
        self.integral = 0.0
        self.last_error = 0.0

    def update(self, setpoint, measured):
        now = time.ticks_ms()
        dt = time.ticks_diff(now, self.last_time) / 1000.0
        if dt <= 0:
            dt = 0.001
        self.last_time = now

        error = setpoint - measured
        self.integral += error * dt
        # anti-windup clamp
        self.integral = max(-1000, min(1000, self.integral))
        derivative = (error - self.last_error) / dt
        self.last_error = error

        output = self.kp * error + self.ki * self.integral + self.kd * derivative
        return max(self.out_min, min(self.out_max, output))
    

    # the state
    class ChannelState:
        def __init__(self):
        self.set_v_mv = 0
        self.set_i_ma = I_OUT_MAX_MA
        self.meas_v_mv = 0.0
        self.meas_i_ma = 0.0
        self.cv_duty = 0
        self.cc_duty = 0
        self.in_cc_mode = False
        self.output_enabled = False
        self.faults = FAULT_NONE

channels = [ChannelState() for _ in range(3)]

sys_state = {
     "input_v_mv": 0.0,
     "input_i_ma": 0.0,
     "BOARD_TEMP_C": 0.0,
        "fan_duty": 0,
    "main_relay_on": False,
    "global fualts": FAULT_NONE
    "self_test_passed": False,
}


# this had to be edited as soon as i got expermient the hardware
cv_pid = [PID(kp=0.8, ki=0.15, kd=0.02, out_min=0, out_max=PWM_DUTY_MAX) for _ in range(3)]


#=-=-=-=-=-=-=-=-=-=-=-=-=-=
#the hardware initialziation

pwm-objs = {}
Relay_pins = {}
encoder_pins = {}
encoder_state = {}   # name -> {"last_clk":.., "delta":0}


def init_pwm():
    for name, pin in PWM_PINS.items():
        p = PWM(Pin(pin), freq=PWM_FREQ)
        p.duty(0)
        pwm_objs[name] = p

def init_relays():
    for name, pin in RELAY_PINS.items():
        r = Pin(pin, Pin.OUT)
        r.value(0)
        relay_pins[name] = r

def set_relay(name, on):
    relay_pins[name].value(1 if on else 0)
    if name == "main":
        sys_state["main_relay_engaged"] = on
    else:
        idx = {"out1": 0, "out2": 1, "out3": 2}[name]
        channels[idx].output_enabled = on

def trip_all_relays():
    for name in relay_pins:
        set_relay(name, False)


def encoder_irq(pin_name):
    def handler(pin):
        clk_pin, dt_pin, _ = encoder_pins[pin_name]
        state = encoder_state[pin_name]
        now = time.ticks_us()
        if time.ticks_diff(now, state["last_us"]) < 1200:
            return
        state["last_us"] = now
        if dt_pin.value():
            state["delta"] += 1
        else:
            state["delta"] -= 1
    return handler

def init_encoders():
    for name, (clk, dt, sw) in ENCODER_PINS.items():
        clk_pin = Pin(clk, Pin.IN, Pin.PULL_UP)
        dt_pin  = Pin(dt,  Pin.IN, Pin.PULL_UP)
        sw_pin  = Pin(sw,  Pin.IN, Pin.PULL_UP)
        encoder_pins[name] = (clk_pin, dt_pin, sw_pin)
        encoder_state[name] = {"delta": 0, "last_us": 0, "last_sw": True}
        clk_pin.irq(trigger=Pin.IRQ_RISING, handler=encoder_irq(name))

def read_encoder_delta(name):
    d = encoder_state[name]["delta"]
    encoder_state[name]["delta"] = 0
    return d

def read_encoder_pressed(name):
    sw_pin = encoder_pins[name][2]
    pressed = not sw_pin.value()
    was_pressed = not encoder_state[name]["last_sw"]
    encoder_state[name]["last_sw"] = sw_pin.value()
    return pressed and not was_pressed


buzzer_protect = None
buzzer_revpol = None

def init_buzzers():
    global buzzer_protect, buzzer_revpol
    buzzer_protect = PWM(Pin(BUZZER_PROTECT_PIN), freq=2000, duty=0)
    buzzer_revpol  = PWM(Pin(BUZZER_REVPOL_PIN), freq=2000, duty=0)

def beep(buzzer, freq, ms):
    buzzer.freq(freq)
    buzzer.duty(512)
    time.sleep_ms(ms)
    buzzer.duty(0)

def alarm_fault():
    beep(buzzer_protect, 2500, 120)
    time.sleep_ms(80)
    beep(buzzer_protect, 2500, 120)

def alarm_reverse_polarity():
    for _ in range(3):
        beep(buzzer_revpol, 1500, 100)
        time.sleep_ms(60)

def alarm_startup():
    beep(buzzer_protect, 1200, 80)
    beep(buzzer_protect, 1600, 80)
    beep(buzzer_protect, 2000, 120)

def alarm_shutdown():
    beep(buzzer_protect, 2000, 80)
    beep(buzzer_protect, 1600, 80)
    beep(buzzer_protect, 1200, 120)


fan_pwm = None

def init_fan():
    global fan_pwm
    fan_pwm = PWM(Pin(FAN_PWM_PIN), freq=FAN_FREQ, duty=0)

def update_fan():
    error = sys_state["board_temp_c"] - FAN_TARGET_TEMP_C
    duty8 = 0
    if error > 0:
        duty8 = int(error * FAN_KP)
        duty8 = max(FAN_MIN_DUTY, min(FAN_MAX_DUTY, duty8))
    duty10 = int(duty8 * 1023 / 255)
    fan_pwm.duty(duty10)
    sys_state["fan_duty_pct"] = int(duty8 * 100 / FAN_MAX_DUTY)


ntc_adc = None
revpol_pin = None

def init_sensors():
    global ntc_adc, revpol_pin
    ntc_adc = ADC(Pin(NTC_PIN))
    ntc_adc.atten(ADC.ATTN_11DB)     # full 0-3.3V range
    ntc_adc.width(ADC.WIDTH_12BIT)
    revpol_pin = Pin(REVPOL_PIN, Pin.IN)

def read_temperature_c():
    raw = ntc_adc.read()
    v_adc = (raw / 4095.0) * 3.3
    if v_adc <= 0.001 or v_adc >= 3.3:
        return sys_state["board_temp_c"]  # keep last good value
    r_ntc = NTC_SERIES_OHM * v_adc / (3.3 - v_adc)
    import math
    steinhart = r_ntc / NTC_NOMINAL_OHM
    steinhart = math.log(steinhart)
    steinhart /= NTC_BETA
    steinhart += 1.0 / (NTC_NOMINAL_C + 273.15)
    steinhart = 1.0 / steinhart
    return steinhart - 273.15

# that ads1115 reading must be here so take this in account in case u are changing something later (for sure i won't)
I2C=None

ads1 = None
ads2 = None

def init_i2c_ads():
    global i2c, ads1, ads2
    i2c = I2C(0, scl=Pin(I2C_SCL), sda=Pin(I2C_SDA), freq=400000)
    ads1 = ADS1115(i2c, ADS1_ADDR)
    ads2 = ADS1115(i2c, ADS2_ADDR)
    return ads1.ok and ads2.ok

def update_sensing():
    acs_mid = 2500.0 * ACS712_DIVIDER_RATIO

    if ads1.ok:
        v1 = ads1.read_mv(0) * VSENSE_DIVIDER_RATIO
        i1_adc = ads1.read_mv(1)
        v2 = ads1.read_mv(2) * VSENSE_DIVIDER_RATIO
        i2_adc = ads1.read_mv(3)

        channels[0].meas_v_mv = v1
        channels[1].meas_v_mv = v2
        i1 = max(0.0, ((i1_adc - acs_mid) / ACS712_DIVIDER_RATIO) / ACS712_MV_PER_A * 1000.0)
        i2 = max(0.0, ((i2_adc - acs_mid) / ACS712_DIVIDER_RATIO) / ACS712_MV_PER_A * 1000.0)
        channels[0].meas_i_ma = i1
        channels[1].meas_i_ma = i2

    if ads2.ok:
        v3 = ads2.read_mv(0) * VSENSE_DIVIDER_RATIO
        i3_adc = ads2.read_mv(1)
        v_main = ads2.read_mv(2) * VSENSE_DIVIDER_RATIO
        i_main_adc = ads2.read_mv(3)

        channels[2].meas_v_mv = v3
        i3 = max(0.0, ((i3_adc - acs_mid) / ACS712_DIVIDER_RATIO) / ACS712_MV_PER_A * 1000.0)
        channels[2].meas_i_ma = i3

        sys_state["input_v_mv"] = v_main
        i_main = max(0.0, ((i_main_adc - acs_mid) / ACS712_DIVIDER_RATIO) / ACS712_MV_PER_A * 1000.0)
        sys_state["input_i_ma"] = i_main


# 
#  CV / CC CONTROL for the xl4016
# ════════════════════

CV_NAMES = ["cv1", "cv2", "cv3"]
CC_NAMES = ["cc1", "cc2", "cc3"]

cal_a = PWM_DUTY_MAX * 1.02
cal_b = PWM_DUTY_MAX / (V_OUT_MAX_MV - V_OUT_MIN_MV)
cal_a_cc = PWM_DUTY_MAX * 1.02
cal_b_cc = PWM_DUTY_MAX / I_OUT_MAX_MA

def mv_to_duty(mv):
    duty = cal_a - cal_b * (mv - V_OUT_MIN_MV)
    return int(max(0, min(PWM_DUTY_MAX, duty)))

def ma_to_duty(ma):
    duty = cal_a_cc - cal_b_cc * ma
    return int(max(0, min(PWM_DUTY_MAX, duty)))

def update_cv_cc():
    for idx in range(3):
        ch = channels[idx]
        cv_name = CV_NAMES[idx]
        cc_name = CC_NAMES[idx]

        # CV/CC mode arbitration
        if not ch.in_cc_mode and ch.meas_i_ma >= ch.set_i_ma * 1.02:
            ch.in_cc_mode = True
        elif ch.in_cc_mode and ch.meas_i_ma <= ch.set_i_ma * 0.97:
            ch.in_cc_mode = False

              if ch.output_enabled:
            duty_v = mv_to_duty(ch.set_v_mv)
            ch.cv_duty = duty_v
            pwm_objs[cv_name].duty(int(duty_v * 1023 / PWM_DUTY_MAX))

            duty_i = ma_to_duty(ch.set_i_ma)
            ch.cc_duty = duty_i
            pwm_objs[cc_name].duty(int(duty_i * 1023 / PWM_DUTY_MAX))
        else:
            pwm_objs[cv_name].duty(0)
            pwm_objs[cc_name].duty(0)

# the protection circuit
def check_protection():
    for idx in range(3):
        ch = channels [idx]
        if not ch.output_enabled:
            continue
        if ch.meas_v_mv > OVP_TRIP_MV:
            ch.fualts   if ch.output_enabled:
            duty_v = mv_to_duty(ch.set_v_mv)
            ch.cv_duty = duty_v
            pwm_objs[cv_name].duty(int(duty_v * 1023 / PWM_DUTY_MAX))

            duty_i = ma_to_duty(ch.set_i_ma)
            ch.cc_duty = duty_i
            pwm_objs[cc_name].duty(int(duty_i * 1023 / PWM_DUTY_MAX))
        else:
            pwm_objs[cv_name].duty(0)
            pwm_objs[cc_name].duty(0)









tft = None

def init_display():
    global tft
    spi = SPI(1, baudrate=27000000, sck=Pin(TFT_SCK), mosi=Pin(TFT_MOSI))
    tft = ST7789(spi, Pin(TFT_CS), Pin(TFT_DC), Pin(TFT_RST), TFT_W, TFT_H)
    Pin(TFT_BL, Pin.OUT).value(1)

def show_boot_message(lines):
    tft.fill(COLOR_BLACK)
    for i, line in enumerate(lines):
        tft.text(line, 4, 4 + i * 12, COLOR_WHITE)
    tft.show()

def show_fault_screen(msg):
    tft.fill(COLOR_RED)
    tft.text(msg, 10, 60, COLOR_WHITE)
    tft.show()

def draw_channel(x, y, label, ch):
    tft.text(label, x, y, COLOR_CYAN)
    v_color = COLOR_YELLOW if ch.in_cc_mode else COLOR_GREEN
    tft.text("{:2d}.{:03d}V".format(int(ch.meas_v_mv // 1000), int(ch.meas_v_mv) % 1000), x, y + 12, v_color)
    tft.text("{:1d}.{:03d}A".format(int(ch.meas_i_ma // 1000), int(ch.meas_i_ma) % 1000), x, y + 24, COLOR_WHITE)
    status = ("ON " if ch.output_enabled else "OFF ") + ("[CC]" if ch.in_cc_mode else "[CV]")
    tft.text(status, x, y + 36, COLOR_GREEN if ch.output_enabled else COLOR_RED)

def update_display():
    tft.fill(COLOR_BLACK)
    draw_channel(4, 4, "CH1", channels[0])
    draw_channel(84, 4, "CH2", channels[1])
    draw_channel(164, 4, "CH3", channels[2])

    tft.text("IN {:2d}.{:01d}V {:1d}.{:02d}A".format(
        int(sys_state["input_v_mv"] // 1000), int(sys_state["input_v_mv"] // 100) % 10,
        int(sys_state["input_i_ma"] // 1000), int(sys_state["input_i_ma"] // 10) % 100),
        4, 70, COLOR_WHITE)

    tft.text("T:{:2d}C Fan:{:3d}%".format(int(sys_state["board_temp_c"]), sys_state["fan_duty_pct"]),
              4, 84, COLOR_WHITE)

    if sys_state["global_faults"] != FAULT_NONE:
        tft.text("*** FAULT ACTIVE ***", 4, 100, COLOR_RED)

    tft.show()

def startup_animation():
    for i in range(0, TFT_W, 20):
        tft.fill(COLOR_BLACK)
        tft.rect(0, 50, i, 10, COLOR_GREEN, fill=True)
        tft.text("PSU BOOM starting...", 4, 4, COLOR_WHITE)
        tft.show()
        time.sleep_ms(15)


# ═══════════════════════════════════════════════════════════════════
#  WI-FI / BLUETOOTH / DATA LOGGING — placeholders
# ═══════════════════════════════════════════════════════════════════

def wifi_connect_placeholder(ssid=None, password=None):
    # Fill in real SSID/password and uncomment to enable.
    # if network is not None:
    #     wlan = network.WLAN(network.STA_IF)
    #     wlan.active(True)
    #     wlan.connect(ssid, password)
    #     return wlan
    pass

def bluetooth_init_placeholder():
    # ESP32-S3 supports BLE via the `bluetooth` module (aioble or ubluetooth).
    # import bluetooth
    # ble = bluetooth.BLE()
    # ble.active(True)
    # return ble
    pass

def log_data_placeholder():
    # Example: append a CSV line to flash. Call periodically from main loop
    # if you want a black-box style event/data log.
    # with open("/psu_log.csv", "a") as f:
    #     f.write("{},{},{},{}\n".format(time.time(), channels[0].meas_v_mv,
    #                                     channels[0].meas_i_ma, sys_state["board_temp_c"]))
    pass


# ═══════════════════════════════════════════════════════════════════
#  SELF TEST
# ═══════════════════════════════════════════════════════════════════

def run_self_test():
    show_boot_message(["PSU BOOM booting...", "Checking relays..."])
    time.sleep_ms(200)

    show_boot_message(["PSU BOOM booting...", "Checking ADS1115..."])
    ads_ok = init_i2c_ads()
    time.sleep_ms(200)

    show_boot_message(["PSU BOOM booting...", "Checking fan..."])
    time.sleep_ms(200)

    show_boot_message(["PSU BOOM booting...", "Checking sensors..."])
    time.sleep_ms(200)

    sys_state["self_test_passed"] = ads_ok

    if ads_ok:
        show_boot_message(["Self-test PASSED", "Ready."])
    else:
        show_boot_message(["Self-test FAILED", "ADS1115 not found!", "Check I2C wiring."])
        alarm_fault()
    time.sleep_ms(800)



#  ENCODER -> SETPOINT HANDLI

pending_save = [False, False, False]
last_change_ms = [0, 0, 0]

def handle_encoders():
    for idx in range(3):
        ch = channels[idx]
        cv_delta = read_encoder_delta(CV_NAMES[idx])
        cc_delta = read_encoder_delta(CC_NAMES[idx])

        if cv_delta != 0:
            new_v = ch.set_v_mv + cv_delta * V_STEP_MV
            ch.set_v_mv = max(V_OUT_MIN_MV, min(V_OUT_MAX_MV, new_v))
            pending_save[idx] = True
            last_change_ms[idx] = time.ticks_ms()

        if cc_delta != 0:
            new_i = ch.set_i_ma + cc_delta * I_STEP_MA
            ch.set_i_ma = max(0, min(I_OUT_MAX_MA, new_i))
            pending_save[idx] = True
            last_change_ms[idx] = time.ticks_ms()

        if read_encoder_pressed(CV_NAMES[idx]):
            name = ["out1", "out2", "out3"][idx]
            set_relay(name, not ch.output_enabled)

def setup():
    print("PSU BOOM (MicroPython) booting...")
    init_display()
    init_buzzers()
    init_pwm()
    init_relays()
    init_encoders()
    init_fan()
    init_sensors()

    startup_animation()
    run_self_test()

    if sys_state["self_test_passed"]:
        set_relay("main", True)
        alarm_startup()

    print("Setup complete.")


    def main():
    setup()

    last_sensing_ms = time.ticks_ms()
    last_protection_ms = time.ticks_ms()
    last_display_ms = time.ticks_ms()

    SENSING_INTERVAL_MS = 50
    PROTECTION_INTERVAL_MS = 20
    DISPLAY_INTERVAL_MS = 150

    while True:
        now = time.ticks_ms()

        handle_encoders()

        if time.ticks_diff(now, last_sensing_ms) >= SENSING_INTERVAL_MS:
            last_sensing_ms = now
            update_sensing()
            sys_state["board_temp_c"] = read_temperature_c()

        update_cv_cc()
        update_fan()

        if time.ticks_diff(now, last_protection_ms) >= PROTECTION_INTERVAL_MS:
            last_protection_ms = now
            check_protection()

        if time.ticks_diff(now, last_display_ms) >= DISPLAY_INTERVAL_MS:
            last_display_ms = now
            if has_active_fault():
                show_fault_screen("FAULT - check log")
            else:
                update_display()

        # log_data_placeholder()   # uncomment once logging destination is set up
        gc.collect()
        time.sleep_ms(2)


if __name__ == "__main__":
    main()

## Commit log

2026-07-18 Create pcbs
2026-07-18 Rename Screenshot 2026-07-18 052406.png to Controll rail shematic
2026-07-18 Rename Screenshot 2026-07-18 040531.png to Power rail shematic
2026-07-18 Rename BOOM/CSV format to BOM.CSV
    [BOM.CSV]
2026-07-19 Enhance README with assembly images and instructions
    Added images and instructions for assembly process in README.
